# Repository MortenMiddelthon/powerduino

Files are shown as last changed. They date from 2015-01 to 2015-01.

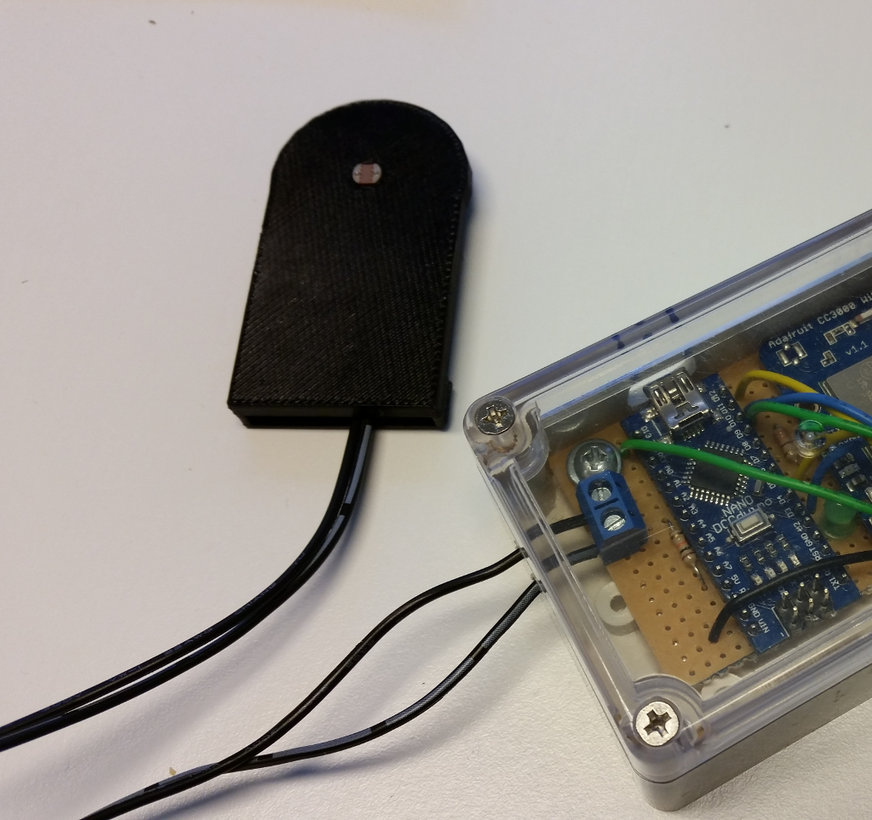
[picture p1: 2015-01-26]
images/powerduino01.png

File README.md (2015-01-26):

# powerduino

Please check the GitHub site for all the examples and required files:

https://github.com/MortenMiddelthon/powerduino

Monitor power usage (kWh) with Arduino and Nagios / Icinga

This project includes the following components:
- Arduino code for reading a photo resistor pulse and write output over USB serial
- Icinga/Nagios plugin for reading USB serial output from the Arduino.
- Icinga/nagios configuration example
- MySQL/MariaDB database definition

Arduino setup
-------------
The included code assumes that the photo resitor is connected to analog input pin 0, but you
can easily alter the code if you want to use another pin. Use a 10K ohm pull down resistor 
connected to ground. The Arduino will output it's reading over USB serial.
To get a proper fit over the pulse light from your power meter you can print out and use the
included 3D model

Adafruit has en excellent tutorial on how to connect a photo resistor to an Arduino:

https://learn.adafruit.com/photocells/using-a-photocell

Parts list:
-----------
- Arduino board, f.ex Micro, Adafruit Pro Trinket or similar:
	- http://www.adafruit.com/product/2000
	- http://www.adafruit.com/products/1086
- 5mm photo resistor:
	- http://www.adafruit.com/product/161
- Two pin terminal block:
	- http://www.adafruit.com/products/724
- Wiring
- 10k Ohm resistor:
	- http://goo.gl/ptRL7R
- Perf/proto/breadboard:
	- http://www.adafruit.com/categories/124

Icinga/nagios setup
-------------------
The included perl script will try to read from the USB port where the Arduino is connected. 
With my Arduino Nano this was /dev/ttyUSB0, but you might have to change this.
The user running the script must be in the dialout group (on Debian at least), and I run it using 
screen:

/usr/bin/screen -S powerusage YOURPATH/readpowerusage.pl

Detach from screen using ctrl+a+d.

This script will continuously read from the USB port and write the power usage readings to
the MySQL/MariaDB database. Please remember to adjust the SQL username/password/database settings
to your environment.

The included icinga/nagios perl plugin reads from the SQL database and outputs power usage
readings to the icinga/nagios, along with performance data. I personally recommend pnp4nagios 
to graph the performance data.

MySQL/MariaDB setup
-------------------
To set up the database use the following commands. These settings must be updated in the included
perl scripts:

% mysql -uroot -p

mysql> create database powerusage;

mysql> grant all on powerusage.* to power@localhost identified by 'YOURPASSWORD';

% mysql -uroot -p powerusage < sql/powerusage.sql

In the table called 'manualreading' enter the current value from your power meter, in kWh:

mysql> insert into manualreading (kwh,timestamp) values (YOURPOWERREADING, UNIX_TIMESTAMP());

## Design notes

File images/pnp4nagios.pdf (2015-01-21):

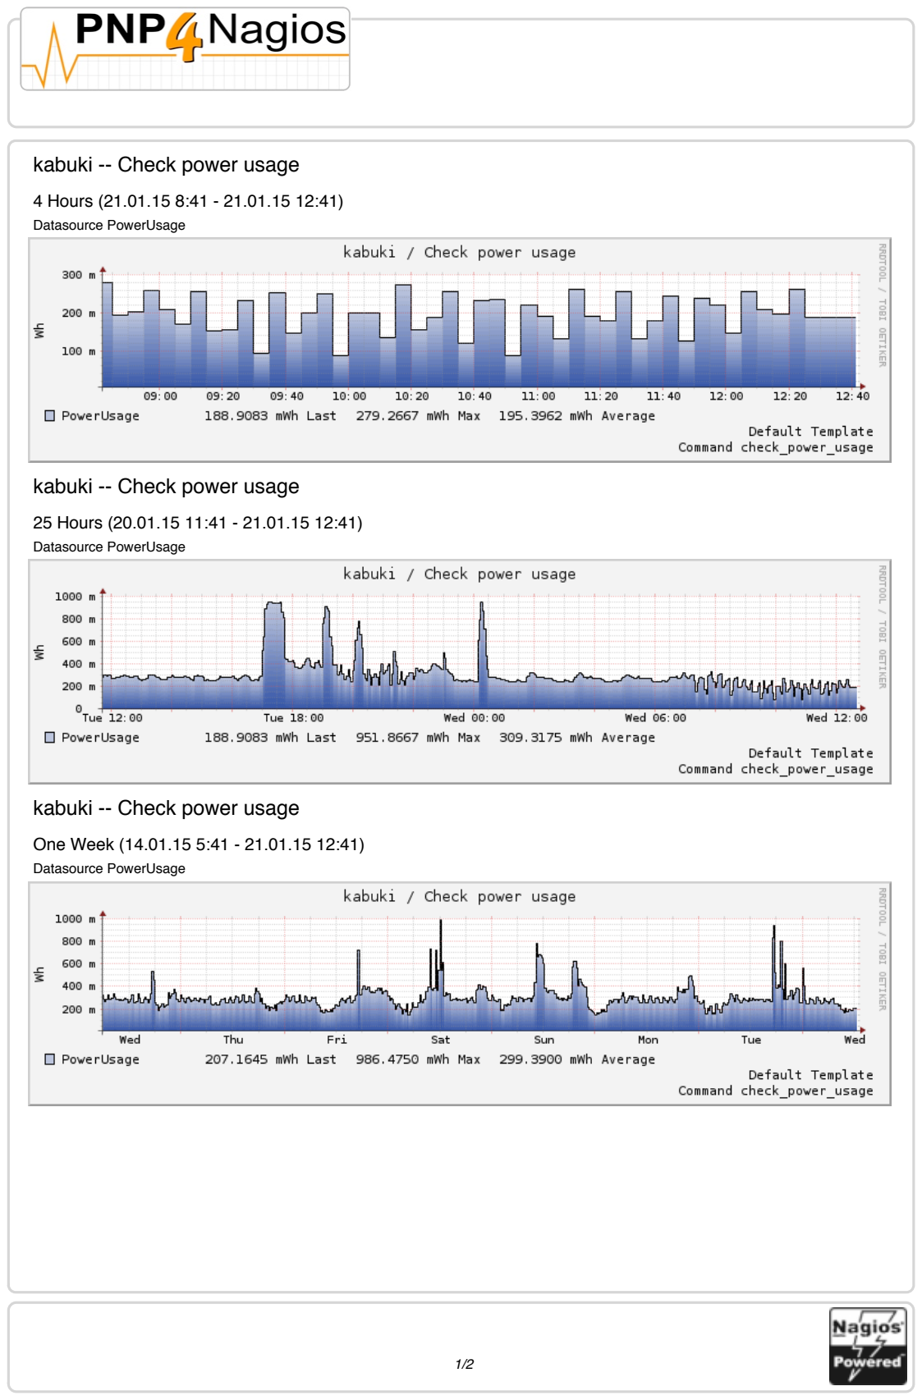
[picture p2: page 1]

### kabuki -- Check power usage

4 Hours (21.01.15 8:41 - 21.01.15 12:41)

Datasource PowerUsage

### kabuki -- Check power usage

25 Hours (20.01.15 11:41 - 21.01.15 12:41)

Datasource PowerUsage

### kabuki -- Check power usage

One Week (14.01.15 5:41 - 21.01.15 12:41)

Datasource PowerUsage

1/2

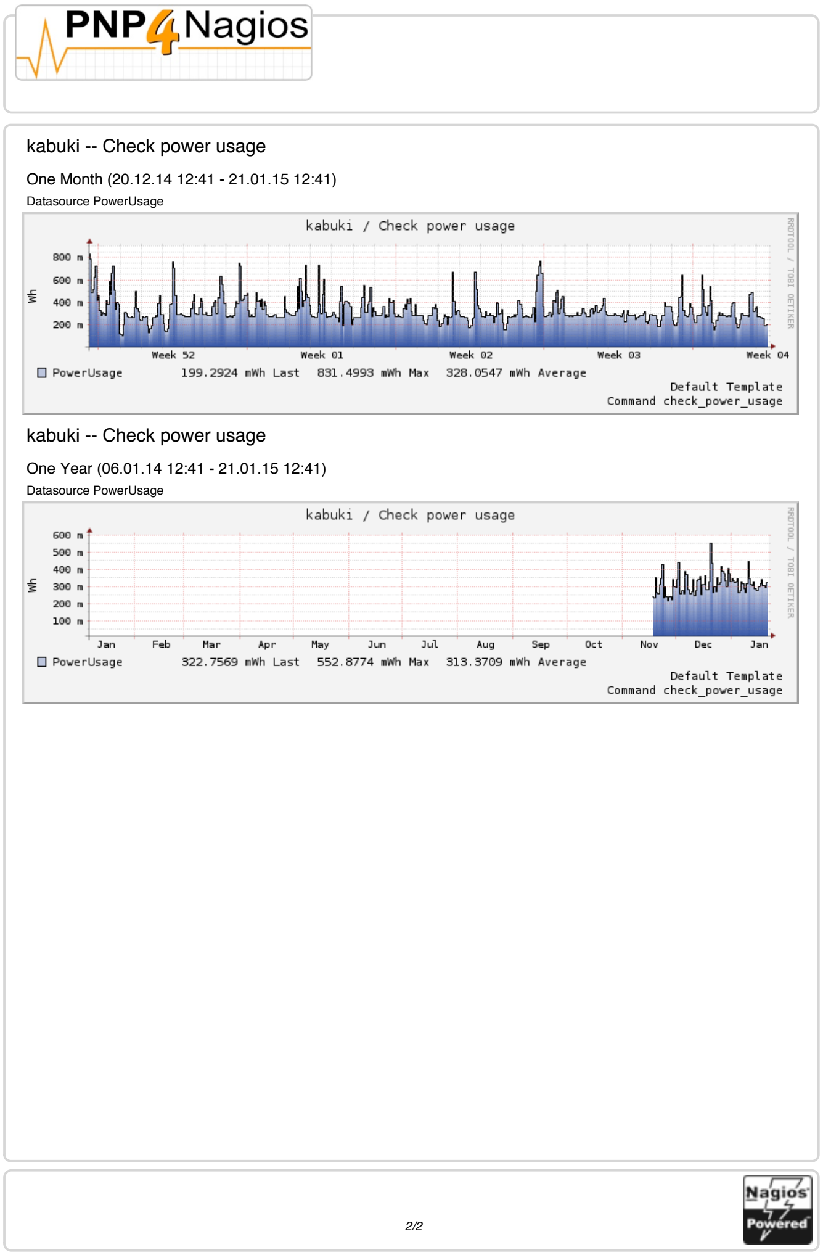
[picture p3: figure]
kabuki -- Check power usage; Datasource PowerUsage

One Month (20.12.14 12:41 - 21.01.15 12:41)

One Year (06.01.14 12:41 - 21.01.15 12:41)

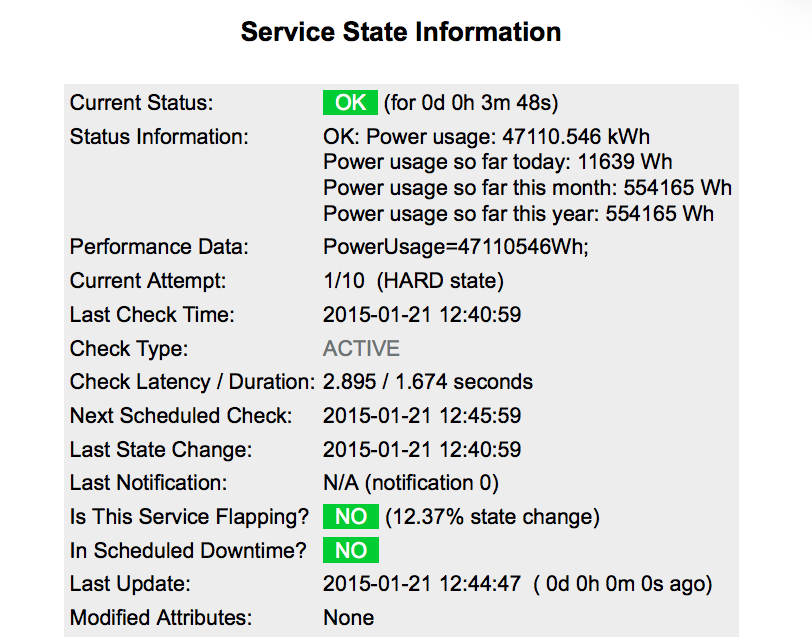
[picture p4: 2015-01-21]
images/icinga_screenshot.png

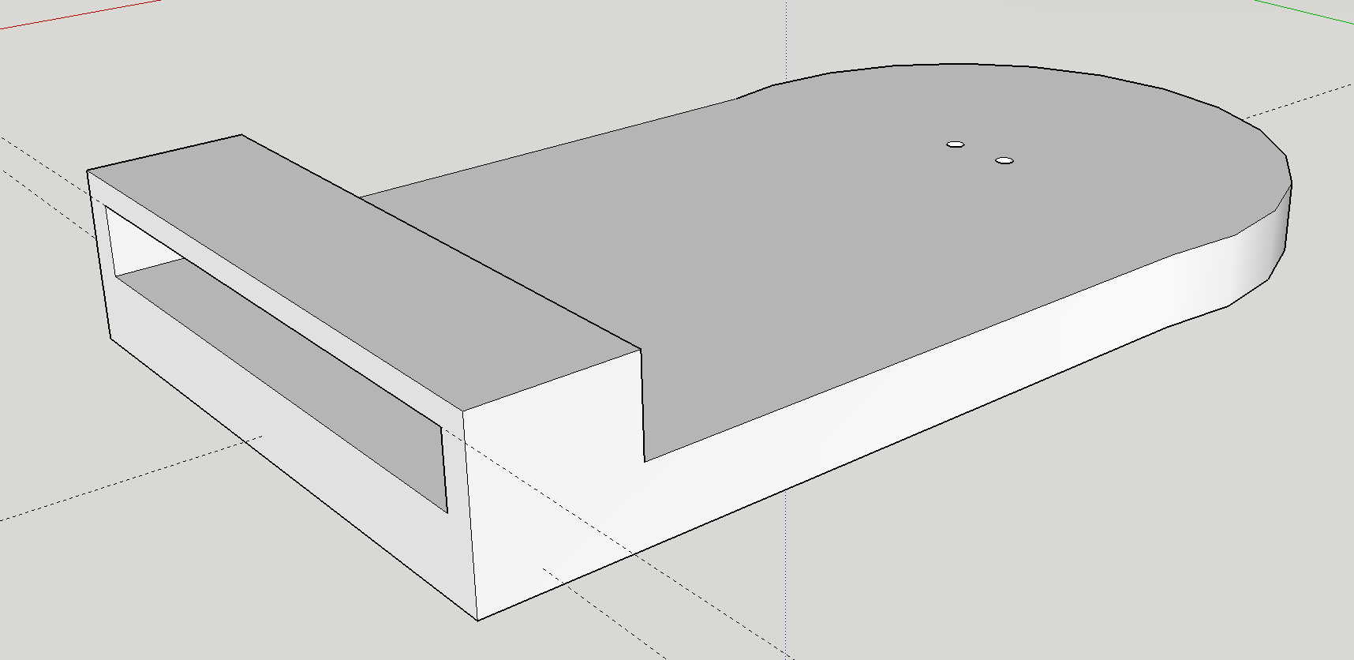
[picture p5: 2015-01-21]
images/3D-model.png

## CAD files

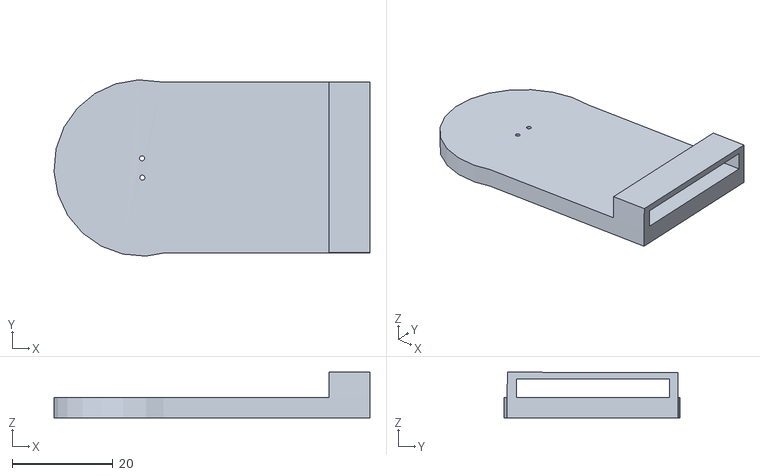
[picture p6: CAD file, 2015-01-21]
3D/photoresistor_holder.stl
62.7 x 35.0 x 9.04

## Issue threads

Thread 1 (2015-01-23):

Arduino hardware "photo resitor"

tobru, 2015-01-23:
Hi,

Thanks a lot for sharing this very interesting project. Could you please add some more information about the "photo resitor", what exactly are you using here? Maybe a little diagram which shows how to connect things to the arduino would also help (I'm really a beginner here).
Also interesting would be to have a short description how the data collection with the photo resistor works: How does it count the power usage? Is every "flash" from the power counter 1Wh?

MortenMiddelthon, 2015-01-23:
Hi there,

Yes, the info is a little lacking. I'll do an update to the project documentation this weekend

With regards, Morten

Sent from my Samsung device

-------- Original message --------
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

MortenMiddelthon, 2015-01-26:
Hi,

I just updated the README-file with a parts list

MortenMiddelthon, 2015-01-26:
Also added a picture of how I have connected everything up:

https://github.com/MortenMiddelthon/powerduino/blob/master/images/powerduino01.png

Closed 2015-02-05.

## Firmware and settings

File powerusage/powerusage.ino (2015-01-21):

// Set the analog input pin where the photo resistor is connected
#define PHOTO 0

uint32_t timestamp;
uint32_t interval = 60000;
uint16_t counter = 0;
uint8_t c = 0;

// The light_state variable determines when the photo resistor has detected a pulse
// This is to avoid counting one pulse more than once
uint8_t light_state = 0;

// Set the photo resistor light threshold. This may have to be adjusted to your 
// environment
uint16_t threshold = 180;

void setup() {
	Serial.begin(9600);
	// Set the timestamp to current running time
	timestamp = millis();
	light_state = 0;
}


void loop() {
	uint16_t light = analogRead(PHOTO);
	// If time interval has been reached, print out the current pulse count
	if(millis() > timestamp + interval) {
		timestamp = millis();
		Serial.println();
		Serial.print("#");
		Serial.print(c);
		Serial.print(" Blinks: ");
		Serial.println(counter);
		counter = 0;
		if(c >= 255) {
			c = 0;
		}
		else {
			c++;
		}
	}
	// Count the pulse if light as above threshold value
	if(light > threshold && light_state == 0) {
		light_state = 1;
		counter++;
		Serial.println(light);
	}
	else if(light < threshold) {
		light_state = 0;
	}
	delay(5);
}

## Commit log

2015-01-21 Initial Arduino code import
2015-01-21 Icinga/nagios config example
    [powerduino.cfg]
2015-01-21 3D model of 5mm photo resistor mount
    [photoresistor_holder.stl]
2015-01-21 Add process_perf_data to icinga config
    [powerduino.cfg]
